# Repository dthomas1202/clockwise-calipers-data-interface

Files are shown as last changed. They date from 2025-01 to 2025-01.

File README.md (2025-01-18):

# Data Interface for Clockwise Tools Caliper Gauges

Easily transfer measurements from Clockwise Tools calipers to your computer for applications like measurement logging, CAD modeling, or manufacturing workflows.

This project is a reverse-engineered version of the Clockwise Tools DTCR-02 RS232 Data Cable for Clockwise tools DCLR-XX05 calipers.
And given the similarity to [liba2k's VINCA Reader](https://github.com/liba2k/VINCA_reader) it seems likely that this Data Interface will work with VINCA series calipers as well.

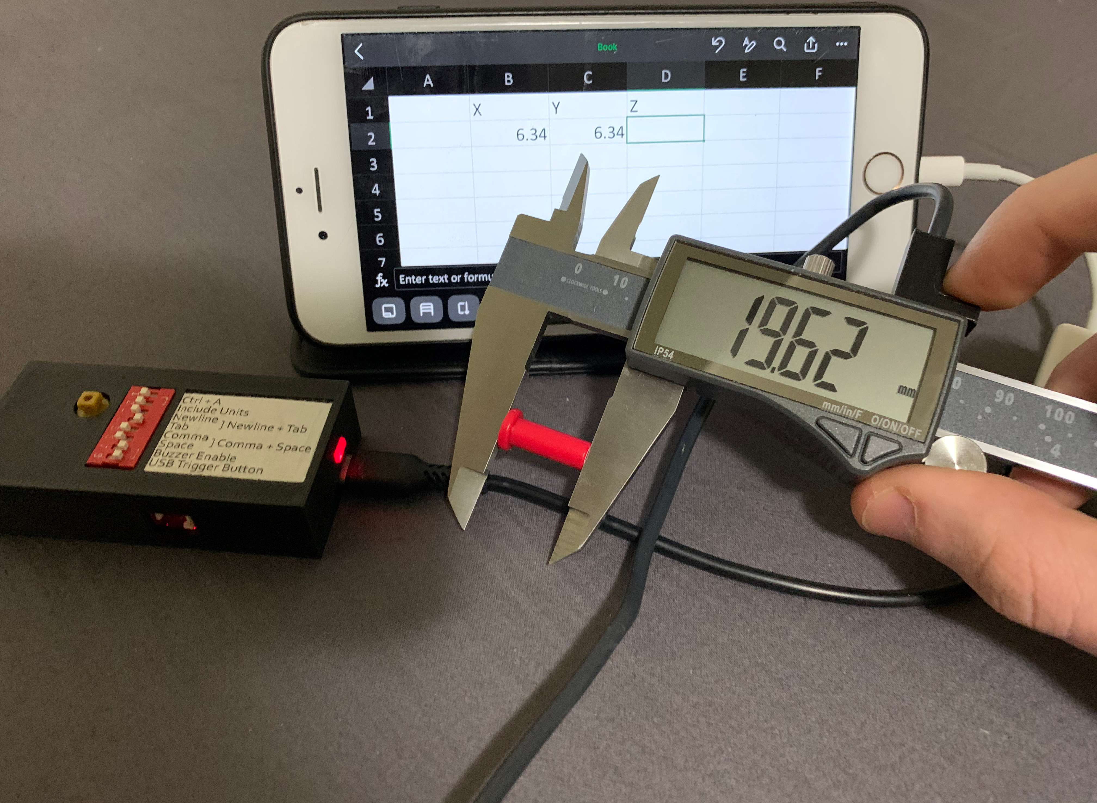
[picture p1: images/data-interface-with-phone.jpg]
Data Interface connected to a iPhone
|  |
|:-:|
| *Data Interface connected to a iPhone running Excel.* |

## Table of Contents

- [Data Interface for Clockwise Tools Caliper Gauges](#data-interface-for-clockwise-tools-caliper-gauges)
  - [Table of Contents](#table-of-contents)
  - [Features](#features)
  - [Hardware](#hardware)
    - [Arduino Support](#arduino-support)
    - [PCB](#pcb)
    - [Case \& USB Cable](#case--usb-cable)
  - [Technical Information](#technical-information)
    - [The "RS232" Serial Protocol](#the-rs232-serial-protocol)
      - [Signal Details](#signal-details)
      - [Protocol Details](#protocol-details)
    - [Potential Improvements](#potential-improvements)
  - [Quirks](#quirks)
    - [iOS Devices](#ios-devices)
    - [Android Devices](#android-devices)

## Features

This project improves on the DTCR-02 Data Cable with enhanced features and flexibility:

- Emulates a generic USB keyboard, compatible with Linux, Windows, macOS, iOS[^1], Android[^1], and really anything that supports USB keyboards.
- Captures and transfers the caliper measurement to any program, such as Excel or CAD software.
- Multiple ways to trigger measurement transfer:
  - Built-in push button.
  - External remote push button or foot pedal (via a 2-pin JST connector).
  - Custom USB cable with a button near the calipers (see schematics for details).
- DIP switch configurable options:
  - `CTRL + A` to overwrite previous measurements.
  - Append units (mm/in) to measurements (e.g., 1.23&nbsp;mm).
  - Add newline, tab, comma, or space after measurements.
  - Enable a buzzer to provide audible feedback when a measurement is sent.
  - Enable the trigger input on the USB ports VBUS pin (see schematics for details).
- Open source allowing full customizability for advanced use cases.

[^1]: See [Quirks](#quirks) for compatibility notes.

## Hardware

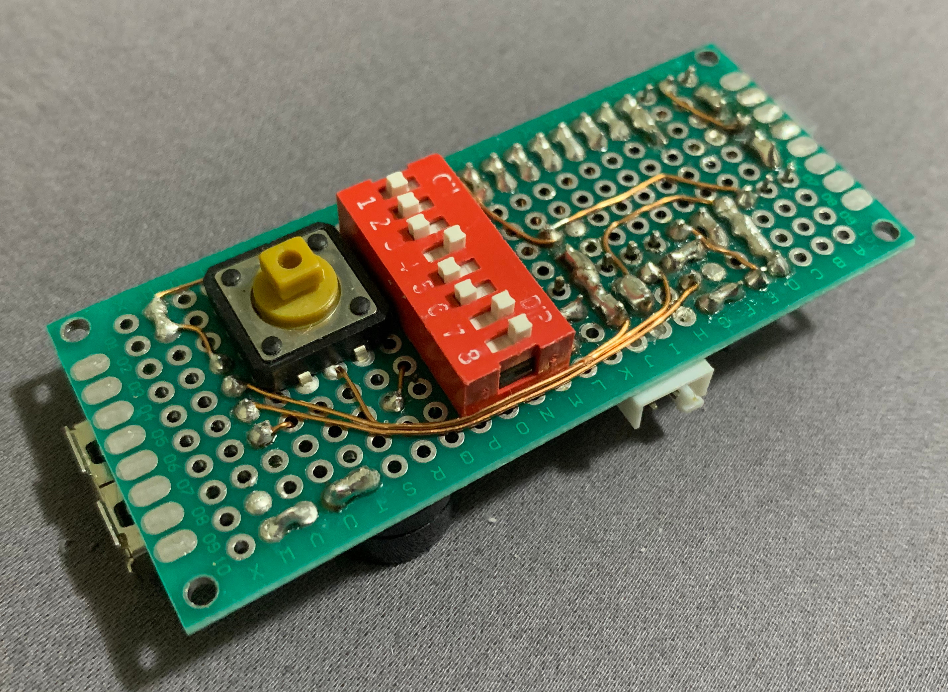
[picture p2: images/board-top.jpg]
Top side of board
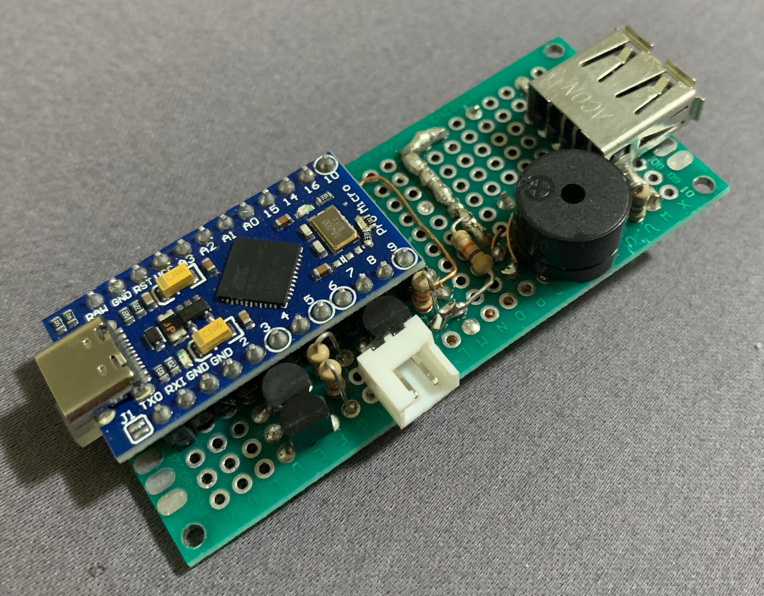
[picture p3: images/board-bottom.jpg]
Bottom side of board
|  |  |
|:-:|:-:|

### Arduino Support

Most Arduino's should be able to read the data stream from the calipers, as the clock rate is relatively slow.

However, in order to emulate a USB keyboard, the Arduino must support native USB communication (Micro, Pro Micro, Leonardo, etc.), or you must use something like [HoodLoader2](https://github.com/NicoHood/HoodLoader2) (See the [Arduino HID Project](https://github.com/NicoHood/HID) for compatibility).

### PCB

As part of the KiCad schematic, there is an example through-hole layout for a double-sided perfboard, as seen in the images above.

KiCad does not support making proper perfboard layouts, so the board is laid out as a PCB, but with components positioned on a 2.54&nbsp;mm grid.
If you intend fabricate an actual PCB, then you probably should not base it off of this.

### Case & USB Cable

3D models are also included for the case and the custom USB cable.
The case was designed to fit these [30x70&nbsp;mm perfboards](https://a.co/d/0OxZCzR) from Amazon, using the board layout provided in the schematic.

The USB cable was designed to fit a 6x6&nbsp;mm tactile push-button and a power only Micro-USB connector that I cut open to use the data pins.

> In both cases, you will likely have to make some modification to the 3D models to suit your own components.

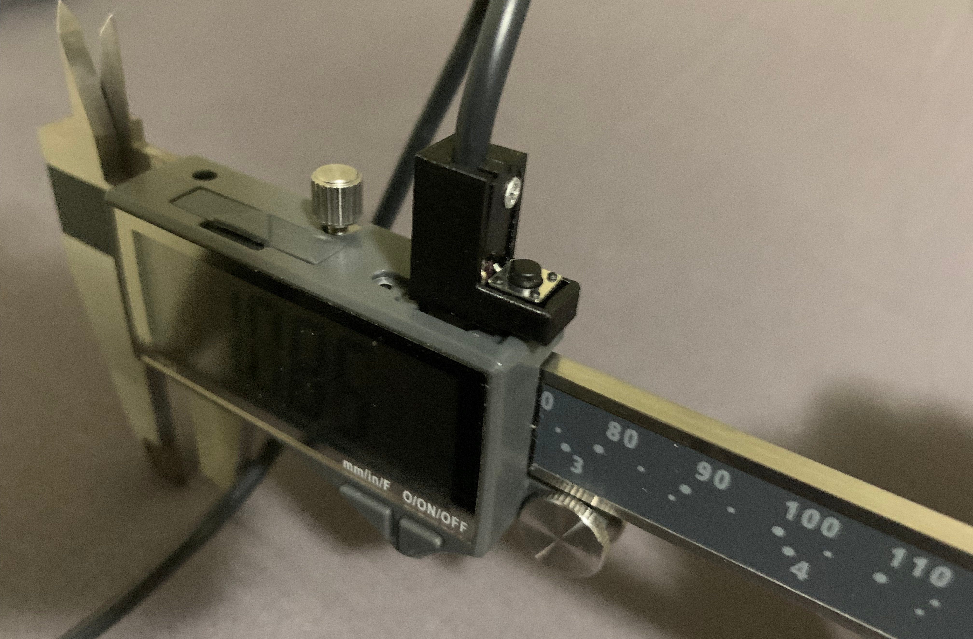
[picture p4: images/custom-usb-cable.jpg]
Custom designed USB cable end
|  |
|:-:|
| *Custom designed USB cable end with integrated trigger button* |

## Technical Information

### The "RS232" Serial Protocol

Clockwise Tools describes the communication as "RS232," but it uses synchronous serial communication over the USB D+ and D- pins. This is effectively equivalent to SPI.

#### Signal Details

- __Clock signal:__ USB D- pin, ~0.4&nbsp;ms per cycle, SPI Mode 3 equivalent.
- __Data signal:__ USB D+ pin, 24-bit (3 x 8-bit) packets, transmitted every ~150&nbsp;ms.
- __+1.5 V:__ USB VBUS pin, constant 1.5&nbsp;V supply.
- All pins operate at 1.5&nbsp;V.
- Clock and data are inverted due to the transistors used for level shifting. So SPI Mode 1 is used in software, and the serial data is inverted.
- Data is transmitted regardless of if the calipers are turned on or not.

> [!WARNING]
> The calipers exhibit weird behavior when too much current is drawn over the USB port.
> This can cause measurements to fluctuate significantly, or the screen to dim.
> Anything connected to the calipers USB port must not draw over __~0.3&nbsp;mA__ of current from all of its pins combined.
> This means that the parallel resistance between VBUS, D+, and D- to GND of the USB connector must be at least ~5&nbsp;kΩ, but preferably well above that.

As far as I can tell, there is no way to communicate from the host device to the calipers, as they are constantly transmitting on D+ and D-, and due to the above, pulling VBUS low causes the calipers to lose power.

#### Protocol Details

- First 4 bits are flags:
  - __Unit:__ Millimeters if 0, Inches if 1.
  - (Unknown use)
  - (Unknown use)
  - __Sign:__ Positive if 0, Negative if 1.
- Last 20 bits are fixed point measurement data:
  - In either hundredths of a millimeter, or
  - 1/2 thousandths of an inch.

The full details are laid out in this article: [Harbor Freight Caliper Data Format](https://www.yuriystoys.com/2013/07/chinese-caliper-data-format.html).

The calipers will send whatever unit is currently selected on the display.
Note that the fraction mode is sent exactly the same as inches.
However, it sends updates less often in fractions mode, presumably since it has to do additional processing for the fractional conversion.

The full implementation of decoding and converting the 24-bit packets can be seen in `ClockwiseCaliper.cpp`.

### Potential Improvements

I designed the schematics and built the device using parts that I had lying around.
Mostly used parts taken from laser printers, coffee makers, and power supplies.
So, given access to the right parts, there are some improvements that can be made to the design.

- The three transistors used to do the voltage level shifting (__Q1__, __Q2__, and __Q3__ in the schematic) should be replaced by MOSFETs.
  The resistors for those transistors should be changed to around 1&nbsp;kΩ.
  And pull-down resistors for the MOSFETs should be added, with values around 100&nbsp;kΩ. This is because of the maximum current requirement as outlined above.

- The calipers can not source over 0.3&nbsp;mA of current from all of its pins, however, I have not tested how much current (if any) it can sink.
  This may be the preferred method for connecting if it works.

- The program could technically use the hardware SPI interface of the Arduino.
  However, without proper timing of the slave select signal, it can cause the data to get out of sync on the first byte.
  This could be solved by controlling the SPI slave select input using another output pin.
  Then activating it on the initial clock pulse, and deactivating it on the last clock pulse.
  However, ensure that the slave select pin is accessible, as Arduino Pro Micro's use that pin for an onboard LED.

## Quirks

### iOS Devices

iOS devices will complain if the USB device reports that it draws more than 100&nbsp;mA over the USB port.
By default, most Arduino's report their bMaxPower USB configuration descriptor to be 500&nbsp;mA.

To change the bMaxPower descriptor you have to change the line `#define USB_CONFIG_POWER (500)` to be 100 or less in `USBCore.h` of the Arduino core files.

Note that for iDevices with a lightning port, a Lightning to USB Camera Adapter (the one with only a USB port) will allow connecting the device, so long as it reports a lower power consumption.

Instead, I have heard that the Lightning to USB 3 Camera Adapter (the one with both a USB port and a lightning port) MAY allow devices that report more than 100&nbsp;mA to work, so long as a charging cable is plugged in.

### Android Devices

I have not tested any Android devices with the Data Interface, but I would assume that with the right adapter, and potentially the iOS bMaxPower tweak above that it would work.

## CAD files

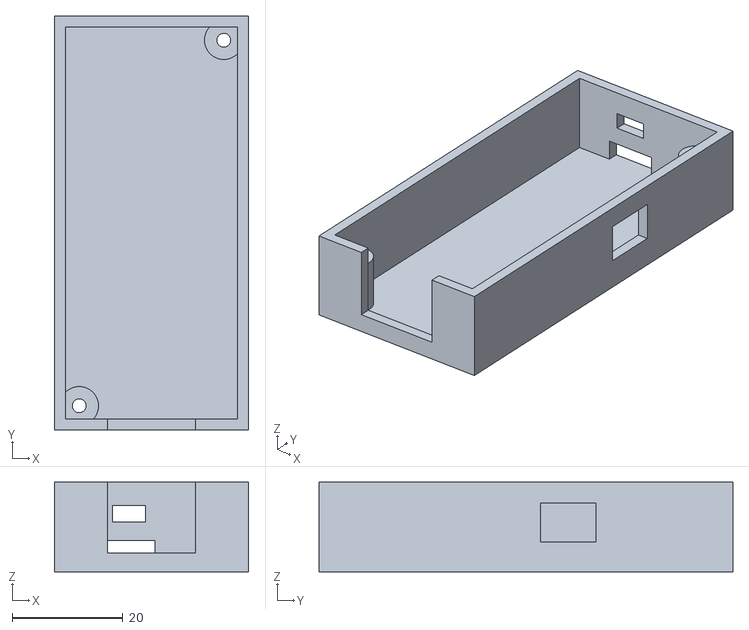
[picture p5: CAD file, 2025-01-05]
3d-models/Case Bottom.stl
35.2 x 74.9 x 16.2

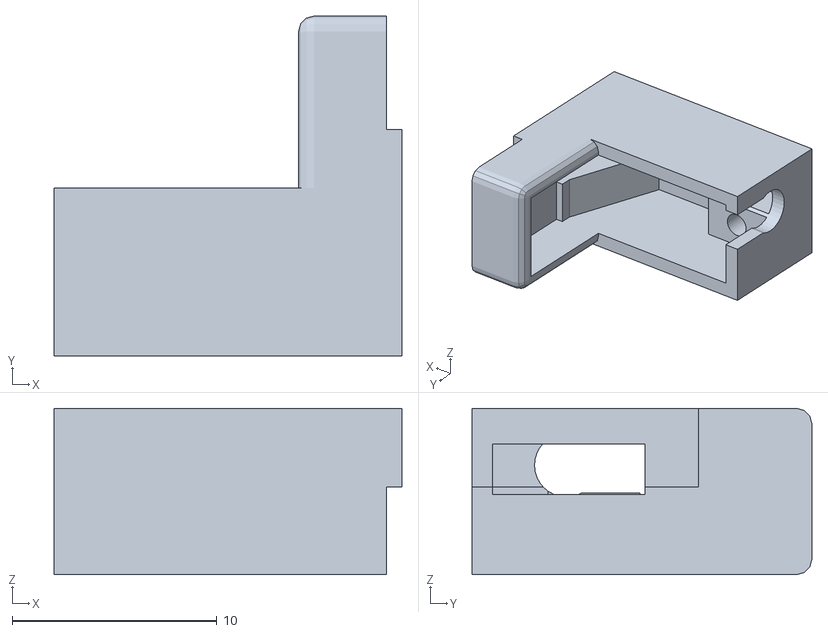
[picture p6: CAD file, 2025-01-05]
3d-models/usb-cable/USB Casing.stl
17.0 x 16.6 x 8.12

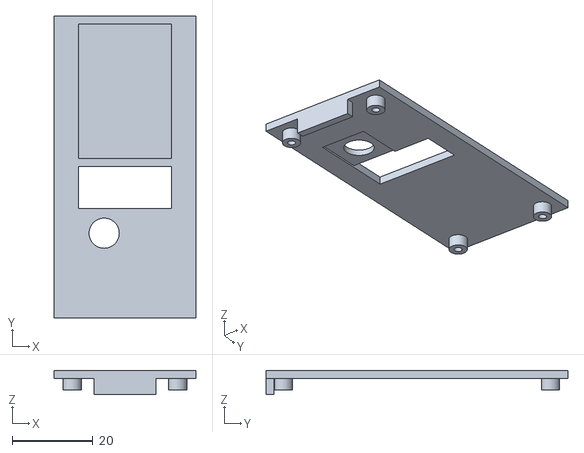
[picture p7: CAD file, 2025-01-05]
3d-models/Case Top.stl
35.2 x 74.9 x 6.00

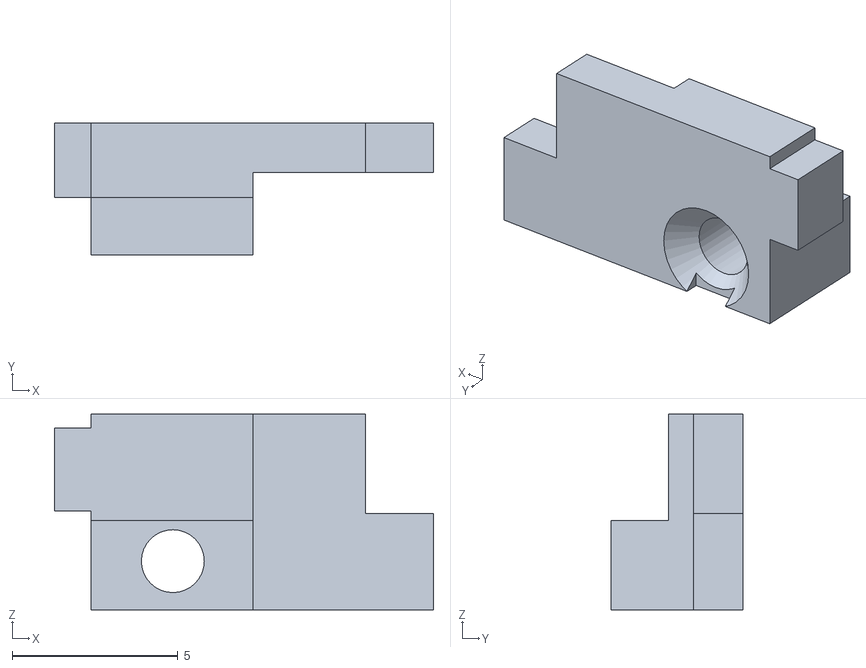
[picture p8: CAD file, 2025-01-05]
3d-models/usb-cable/Insert.stl
11.4 x 4.00 x 5.92

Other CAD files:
3d-models/Case.blend
3d-models/usb-cable/Usb Connector.blend

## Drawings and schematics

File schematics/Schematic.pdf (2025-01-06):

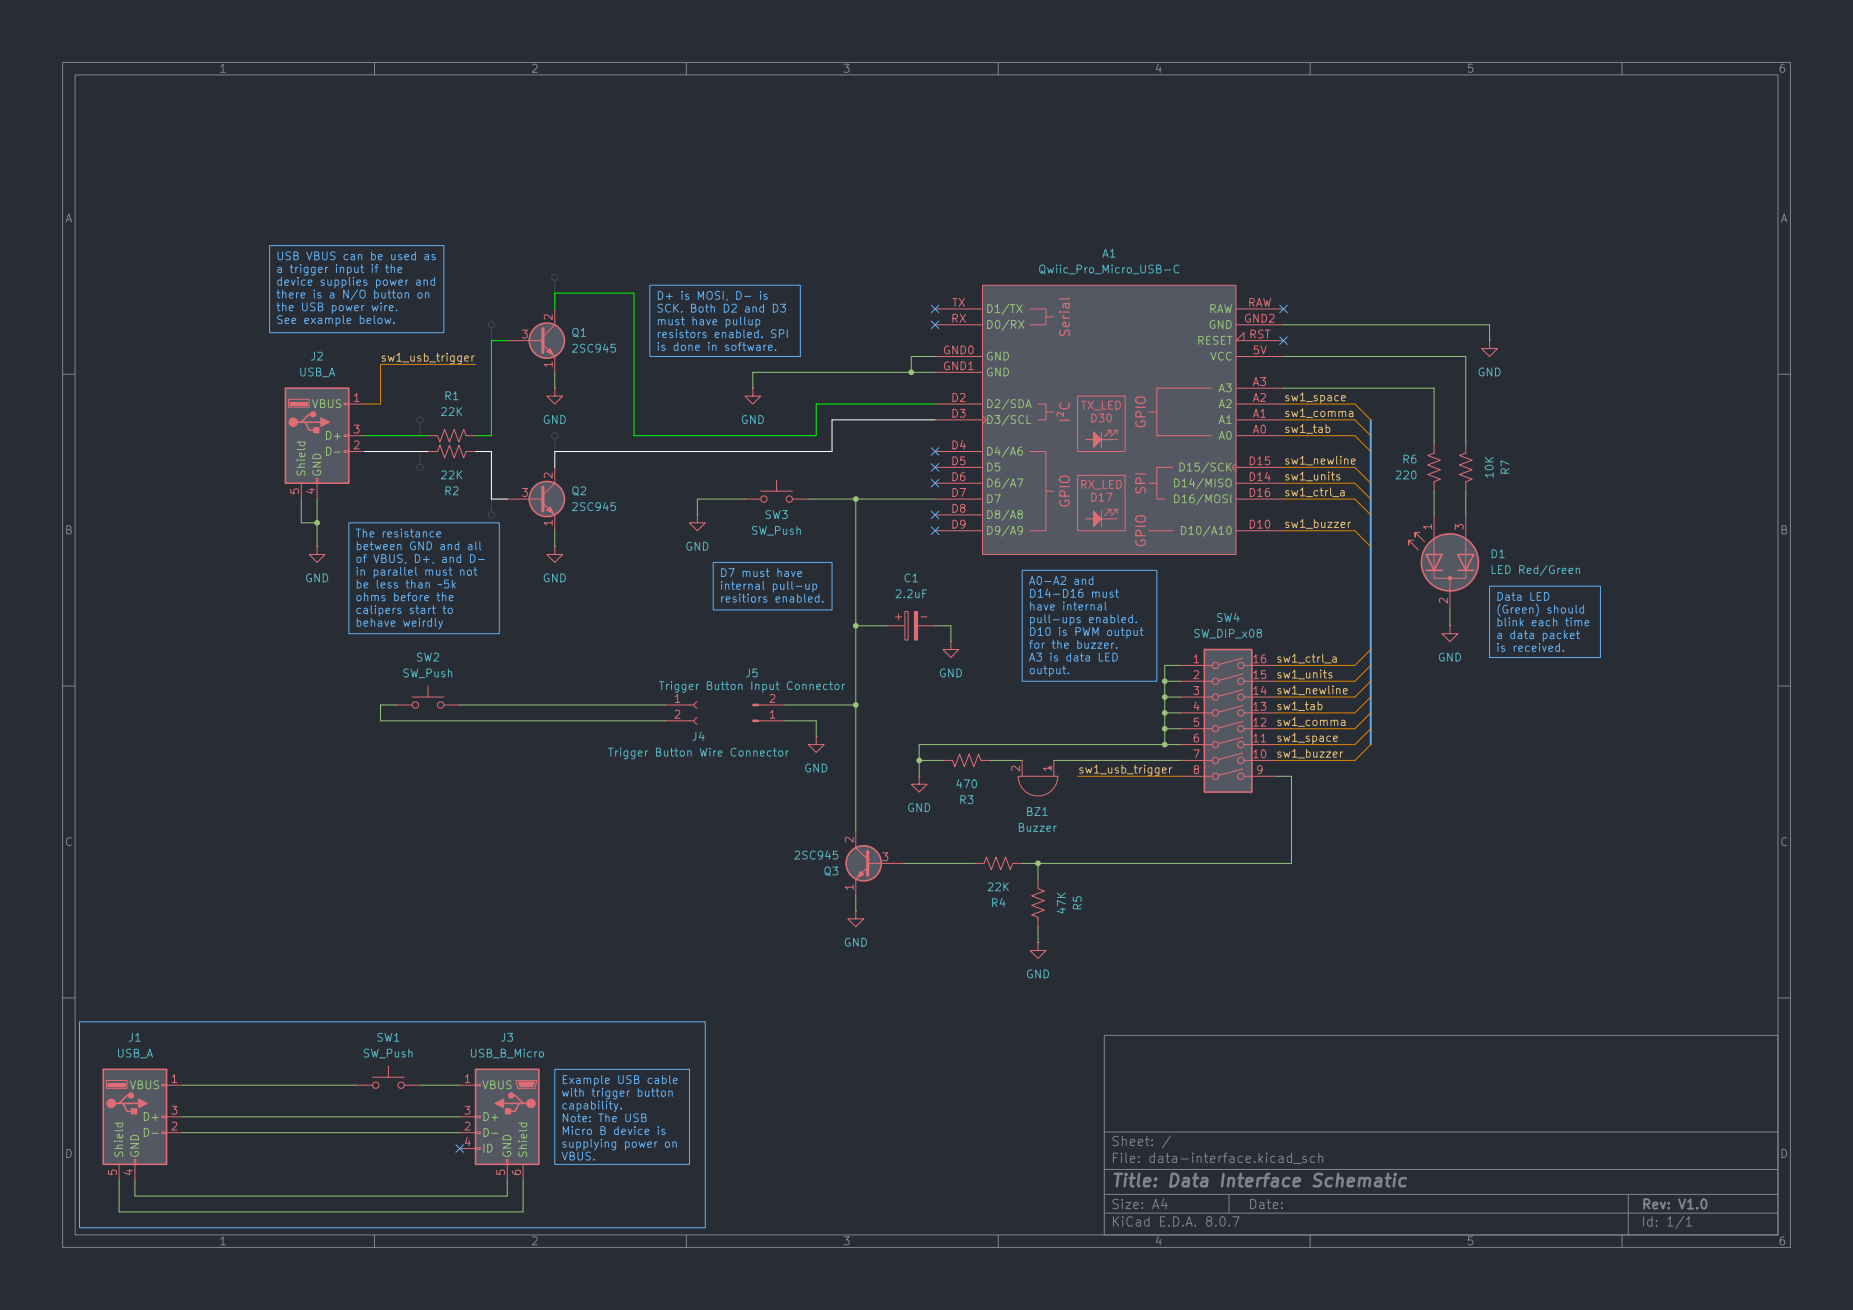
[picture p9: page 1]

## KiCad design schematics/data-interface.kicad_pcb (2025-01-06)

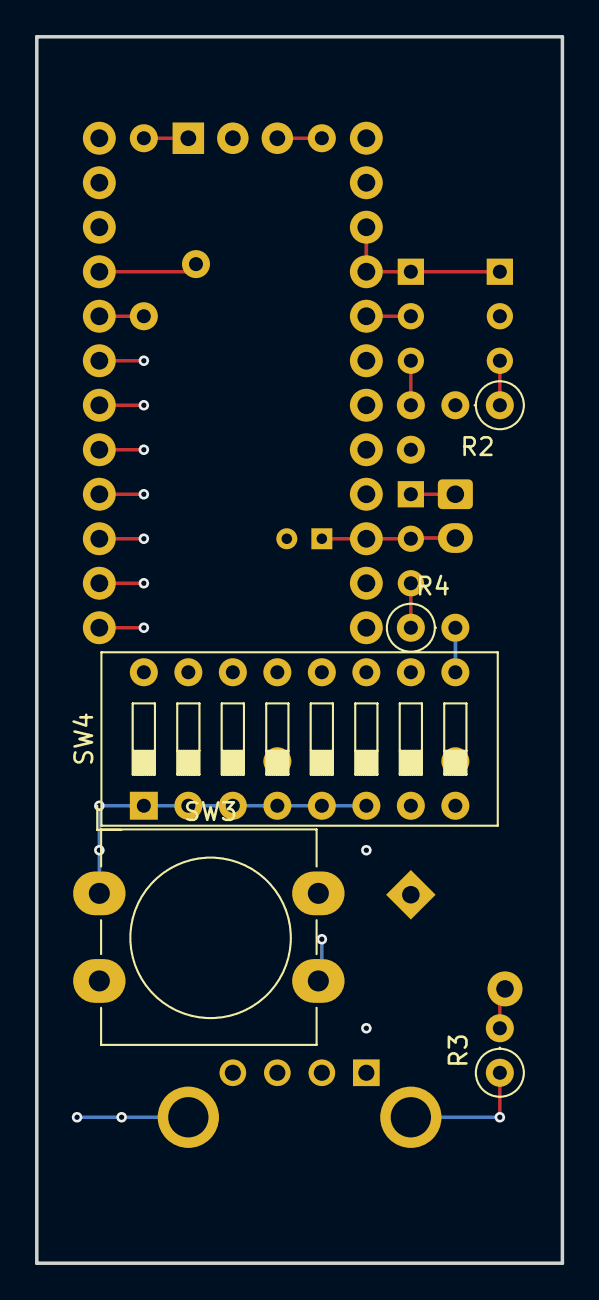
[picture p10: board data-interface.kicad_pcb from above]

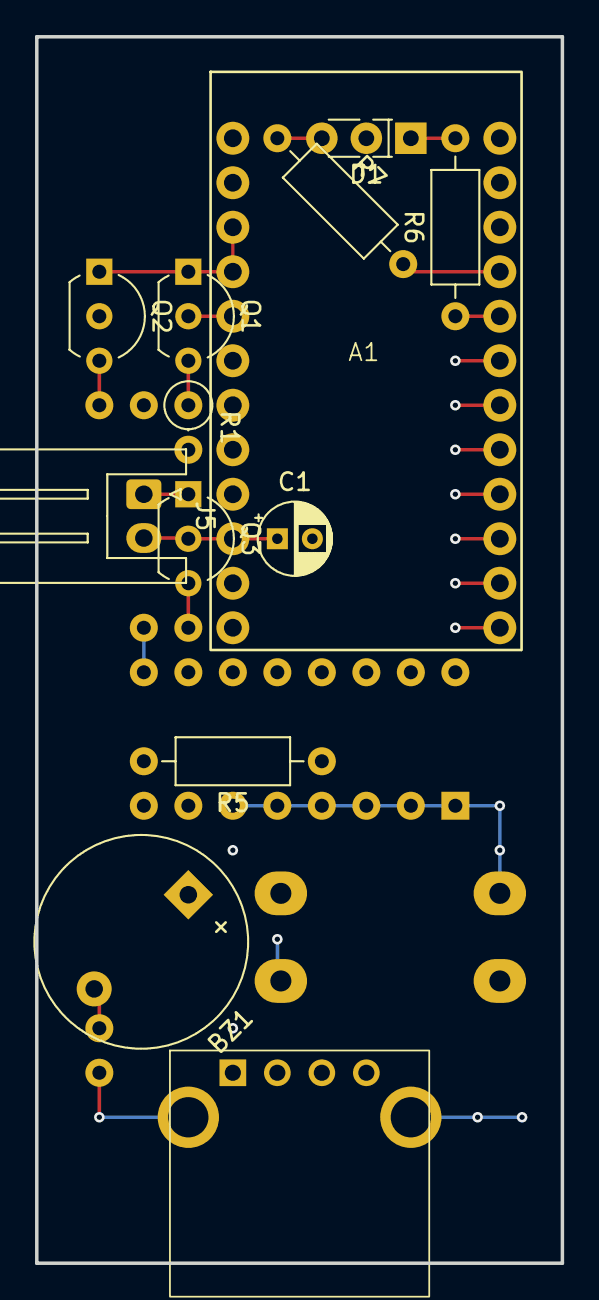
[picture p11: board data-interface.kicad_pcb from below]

Board: 4 copper layers, 30.0 x 70.0 mm, 18 parts (13 on the bottom side), 24 nets.

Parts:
A1: Qwiic_Pro_Micro_USB-C; Qwiic_Pro_Micro_USB-C_Socket
BZ1: Buzzer; Buzzer_12x9.5RM7.6
C1: 2.2uF; CP_Radial_D4.0mm_P2.00mm
D1: LED Red/Green; LED_Rectangular_W5.0mm_H2.0mm-3Pins
J2: USB_A; USB_A_Horizontal
J5: Trigger Button Input Connector; JST_XH_S2B-XH-A_1x02_P2.50mm_Horizontal
Q1, Q2, Q3: 2SC945; TO-92L_Inline_Wide
R1, R2, R4: 22K; R_Axial_DIN0207_L6.3mm_D2.5mm_P2.54mm_Vertical
R3: 470; R_Axial_DIN0207_L6.3mm_D2.5mm_P2.54mm_Vertical
R5: 47K; R_Axial_DIN0207_L6.3mm_D2.5mm_P10.16mm_Horizontal
R6: 220; R_Axial_DIN0207_L6.3mm_D2.5mm_P10.16mm_Horizontal
R7: 10K; R_Axial_DIN0207_L6.3mm_D2.5mm_P10.16mm_Horizontal
SW3: SW_Push; SW_PUSH-12mm_Wuerth-430476085716
SW4: SW_DIP_x08; SW_DIP_SPSTx08_Slide_9.78x22.5mm_W7.62mm_P2.54mm

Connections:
/sw1_buzzer: A1.D10 (D10/A10), SW4.10
/sw1_comma: A1.A1, SW4.12
/sw1_ctrl_a: A1.D16 (D16/MOSI), SW4.16
/sw1_newline: A1.D15 (D15/SCK), SW4.14
/sw1_space: A1.A2, SW4.11
/sw1_tab: A1.A0, SW4.13
/sw1_units: A1.D14 (D14/MISO), SW4.15
/sw1_usb_trigger: J2.1 (VBUS), SW4.8
GND: A1.GND0 (GND), A1.GND1 (GND), A1.GND2 (GND), C1.2, D1.2 (K), J2.4 (GND), J2.5 (Shield), J5.1, Q1.1 (E), Q2.1 (E), Q3.1 (E), R3.1, R5.1, SW3.1, SW4.1, SW4.2, SW4.3, SW4.4, SW4.5, SW4.6
unnamed: A1.D2 (D2/SDA), Q1.2 (C)
unnamed: A1.D3 (D3/SCL), Q2.2 (C)
unnamed: A1.A3, R6.1
unnamed: A1.5V (VCC), R7.2
unnamed: BZ1.1 (+), SW4.7
unnamed: BZ1.2 (-), R3.2
unnamed: D1.1 (A1), R6.2
unnamed: D1.3 (A2), R7.1
unnamed: J2.3 (D+), R1.2
unnamed: J2.2 (D-), R2.2
unnamed: A1.D7, C1.1, J5.2, Q3.2 (C), SW3.2
unnamed: Q1.3 (B), R1.1
unnamed: Q2.3 (B), R2.1
unnamed: Q3.3 (B), R4.1
unnamed: R4.2, R5.2, SW4.9

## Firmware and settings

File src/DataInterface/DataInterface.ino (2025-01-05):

/*
 * DataInterface.ino - Clockwise Calipers Data Interface
 * Copyright (C) 2025  Diesel Thomas
 *
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
 * You should have received a copy of the GNU General Public License
 * along with this program.  If not, see <https://www.gnu.org/licenses/>.
 */

/*
 * NOTE: To achieve compatibility with mobile devices, such as Apple
 * iDevices, the bMaxPower USB configuration descriptor must be lowered
 * so the device accepts the Arduino. Currently, to do this the line
 *   #define USB_CONFIG_POWER (500)
 * must be changed to less than 100 in USBCore.h of the Arduino core
 * library.
 */


#include "ClockwiseCaliper.h"
#include "SoftSPISlave.h"
#include <HID-Project.h>

// #define DEBUG_SERIAL

#ifdef DEBUG_SERIAL
    #define debug_println(...) Serial.println(__VA_ARGS__)
    #define debug_print(...) Serial.print(__VA_ARGS__)
#else
    #define debug_println(...)
    #define debug_print(...)
#endif


// Caliper SPI like data
const uint8_t CLK_PIN = 3; // Serial clock pin (must support interrupts)
const uint8_t DATA_PIN = 2; // Serial data pin (must support interrupts)
const uint32_t BIT_MAX_DELAY = 10; // Milliseconds - Maximum time between spi clock pulses
const uint32_t PACKET_MAX_DELAY = 10; // Milliseconds - Maximum time between 8 bit packets

// DIP switch control pins
const uint8_t DIP_CTRL_A_PIN = 16; // Type CTRL+A before the measurement
const uint8_t DIP_UNITS_PIN = 14; // Type the units after the measurement
const uint8_t DIP_NEWLINE_PIN = 15; // Type a newline after the measurement
const uint8_t DIP_TAB_PIN = A0; // Type a tab after the measurement
const uint8_t DIP_COMMA_PIN = A1; // Type a comma after the measurement
const uint8_t DIP_SPACE_PIN = A2; // Type a space after the measurement
// Any of newline, tab, comma, and space can be combined to in that order
const bool DIP_ON_STATE = LOW; // Switch is active when it is in this state

const uint8_t TRIGGER_PIN = 7; // Triggers typing the measurement (should support interrupts)
const uint8_t TRIGGER_PIN_INT_MODE = FALLING; // When to trigger the interrupt (either RISING or FALLING)
// NOTE: You can rewrite this for TRIGGER_PIN to not require interrupts, its just real convenient

const uint8_t DATA_LED_PIN = A3; // LED to blink when data is r * <one line to give the program's name and a brief idea of what it does.>
const bool DATA_LED_ACTIVE_STATE = HIGH; // State to use when data LED is ON

const uint8_t BUZZER_PIN = 10; // Passive buzzer to sound when data is typed (must support pwm)
const uint16_t BUZZER_FREQ = 4000; // Hz - Frequency of buzzer
const uint16_t BUZZER_DURATION = 10; // Milliseconds - Time to sound the buzzer for


uint8_t resyncCounter = 0;
volatile bool triggerFlag = false;

ClockwiseCaliper caliper;
SoftSPISlave softSpi(CLK_PIN, -1, DATA_PIN, -1);


void triggerIsr() {
    triggerFlag = true;
}


void setup() {
    #ifdef DEBUG_SERIAL
        Serial.begin(115200);

        while (!Serial && millis() < 2000) {
            ; // Wait for serial port to connect, or 2 seconds. Needed for native USB
        }
    #endif

    softSpi.begin(false, SSPI_MODE1, SSPI_LSB_FIRST, BIT_MAX_DELAY);

    // Override pinMode from softSpi to enable pullups
    pinMode(CLK_PIN, INPUT_PULLUP);
    pinMode(DATA_PIN, INPUT_PULLUP);

    pinMode(DIP_CTRL_A_PIN, INPUT_PULLUP);
    pinMode(DIP_UNITS_PIN, INPUT_PULLUP);
    pinMode(DIP_NEWLINE_PIN, INPUT_PULLUP);
    pinMode(DIP_TAB_PIN, INPUT_PULLUP);
    pinMode(DIP_COMMA_PIN, INPUT_PULLUP);
    pinMode(DIP_SPACE_PIN, INPUT_PULLUP);

    pinMode(TRIGGER_PIN, INPUT_PULLUP);

    pinMode(DATA_LED_PIN, OUTPUT);
    pinMode(BUZZER_PIN, OUTPUT);

    digitalWrite(DATA_LED_PIN, !DATA_LED_ACTIVE_STATE);

    BootKeyboard.begin();

    debug_println("Starting...");

    tone(BUZZER_PIN, BUZZER_FREQ, BUZZER_DURATION);
    delay(200);
    tone(BUZZER_PIN, BUZZER_FREQ, BUZZER_DURATION);

    // Set last so pins stabilize
    attachInterrupt(digitalPinToInterrupt(TRIGGER_PIN), triggerIsr, TRIGGER_PIN_INT_MODE);
}


void emptySoftSpiBuffer() {
    // Empty RX buffer, we don't know which byte is which
    while (softSpi.rxBytesAvailable() > 0) {
        softSpi.read();
    }
}


void recievePacket() {
    static uint8_t spiDataIndex = 0;
    static uint32_t lastSpiDataTime = 0;

    uint8_t spiData = ~ softSpi.read(); // Invert all bits
    uint32_t currentTime = millis();

    digitalWrite(DATA_LED_PIN, DATA_LED_ACTIVE_STATE);

    if (spiDataIndex > 0 && currentTime - lastSpiDataTime >= PACKET_MAX_DELAY) {
        // Time between packets was too long, resync
        resyncCounter++;
        spiDataIndex = 0;
    }

    caliper.updateByte(spiData, spiDataIndex);
    spiDataIndex++;
    lastSpiDataTime = currentTime;

    if (spiDataIndex >= caliper.getPacketLength()) {
        // Completed packet, reset and update
        spiDataIndex = 0;

        caliper.setNewData();
        digitalWrite(DATA_LED_PIN, !DATA_LED_ACTIVE_STATE);
    }
}


void typeIfPin(KeyboardKeycode key, uint8_t pin) {
    if (digitalRead(pin) == DIP_ON_STATE) {
        BootKeyboard.write(key);
    }
}


void typeMeasurement() {
    // CTRL + A
    if (digitalRead(DIP_CTRL_A_PIN) == DIP_ON_STATE) {
        BootKeyboard.press(KEY_LEFT_CTRL);
        BootKeyboard.press(KEY_A);
        BootKeyboard.releaseAll();
    }

    // Type measurement
    BootKeyboard.print(caliper.getMeasurement(), 4);

    // Units
    if (digitalRead(DIP_UNITS_PIN) == DIP_ON_STATE) {
        BootKeyboard.print(caliper.getUnitString());
    }

    typeIfPin(KEY_ENTER, DIP_NEWLINE_PIN); // Newline
    typeIfPin(KEY_TAB, DIP_TAB_PIN);       // Tab
    typeIfPin(KEY_COMMA, DIP_COMMA_PIN);   // Comma
    typeIfPin(KEY_SPACE, DIP_SPACE_PIN);   // Space

    tone(BUZZER_PIN, BUZZER_FREQ, BUZZER_DURATION);
}


void loop() {
    if (softSpi.rxHasLostData()) {
        emptySoftSpiBuffer();
        debug_println("Lost data, buffer emptied");
    }

    while (softSpi.rxHasData()) {
        recievePacket();
    }

    if (caliper.isNewData()) {
        // Always maintain most recent data
        caliper.refershData();

        debug_print("resync: ");     debug_print(resyncCounter);            debug_print(", ");
        debug_print("spi_resync: "); debug_print(softSpi.getResyncCount()); debug_print(", ");

        debug_print("unit: "); debug_print(caliper.getUnitString());     debug_print(", ");
        debug_print("sign: "); debug_print(caliper.getSignString());     debug_print(", ");
        debug_print("raw: ");  debug_print(caliper.getRawMeasurement()); debug_print(", ");

        debug_print("measurement: "); debug_print(caliper.getMeasurement(), 4); debug_println();
    }

    if (triggerFlag) {
        triggerFlag = false;
        typeMeasurement();
        debug_println("Typed measurement");
    }
}

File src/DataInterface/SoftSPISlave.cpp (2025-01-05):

/*
 * SoftSPISlave.cpp - SPI Slave Implemented in Software
 * Copyright (C) 2025  Diesel Thomas
 *
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
 * You should have received a copy of the GNU General Public License
 * along with this program.  If not, see <https://www.gnu.org/licenses/>.
 */

// WARNING: TX (MISO) functionality is currently untested, as it was only
// implemented for completeness


#include "SoftSPISlave.h"


/**
 * Software SPI slave constructor.
 * The CLK pin must be defined and must be an interrupt capable pin.
 * MISO, MOSI, and SS pins are optional, however, at least one of MISO
 * or MOSI must be defined. Also, if MISO is defined then SS must also
 * be defined and must be an interrupt capable pin.
 *
 * @param clkPin serial clock pin
 * @param misoPin master in, slave out pin
 * @param mosiPin master out, slave in pin
 * @param ssPin slave select pin
 */
SoftSPISlave::SoftSPISlave(int16_t clkPin,
                           int16_t misoPin = -1,
                           int16_t mosiPin = -1,
                           int16_t ssPin = -1) {
    this->clkPin = clkPin;
    this->misoPin = misoPin;
    this->mosiPin = mosiPin;
    this->ssPin = ssPin;


    this->dataIndex = 0;
    this->resyncCount = 0;
    this->rxDataLost = false;
}


/**
 * Starts sending or receiving data on the SPI bus.
 * maxClkTime defines the maximum time to wait for the next clock change
 * while in the middle of a byte. If the time elapses, the current byte
 * is reset to the start for the next clock cycle.
 *
 * @param ssActiveHigh if true, slave select is active when high
 * @param spiMode the SPI clock polarity and phase to use
 * @param spiDataOrder whether the LSB or MSB is first
 * @param maxClkTime milliseconds to wait for another clock before
 *                   resetting. A value of 0 disables this
 */
void SoftSPISlave::begin(bool ssActiveHigh = false,
                         softspi_mode_t spiMode = SSPI_MODE0,
                         softspi_data_order_t spiDataOrder = SSPI_MSB_FIRST,
                         uint32_t maxClkTime = 0) {
    this->ssActiveHigh = ssActiveHigh;
    this->spiCPHA = SoftSPISlave::getBit(spiMode, 0);
    this->spiCPOL = SoftSPISlave::getBit(spiMode, 1);
    this->spiDataOrder = spiDataOrder;
    this->maxClkTime = maxClkTime;

    int16_t clkIntPin = digitalPinToInterrupt(this->clkPin);
    int16_t ssIntPin = digitalPinToInterrupt(this->ssPin);

    if (clkIntPin < 0 // CLK pin is not set, or not an interrupt capable pin
            || (this->misoPin < 0 && this->mosiPin < 0) // At least one of MISO or MOSI is not set
            || (this->misoPin >= 0 && ssIntPin < 0)) { // MISO is defined and SS is not defined or not interrupt capable
        return;
    }

    pinMode(this->clkPin, INPUT);

    if (this->mosiPin >= 0) {
        pinMode(this->mosiPin, INPUT);
    }

    if (this->ssPin >= 0) {
        // SS is defined
        pinMode(this->ssPin, INPUT);

        if (this->misoPin >= 0 && ssIntPin >= 0) {
            // MISO is defined and SS is interrupt capable
            attachInterrupt(ssIntPin, bindArgGateThisAllocate(&SoftSPISlave::ssIsr, this), CHANGE);
        }
    }

    attachInterrupt(clkIntPin, bindArgGateThisAllocate(&SoftSPISlave::clkIsr, this), CHANGE);
}

/**
 * Stops sending or receiving data on the SPI bus.
 */
void SoftSPISlave::end() {
    int16_t clkIntPin = digitalPinToInterrupt(this->clkPin);
    int16_t ssIntPin = digitalPinToInterrupt(this->ssPin);

    detachInterrupt(clkIntPin);

    if (this->misoPin >= 0 && ssIntPin >= 0) {
        // SS would have been setup with interrupts
        detachInterrupt(ssIntPin);
    }

    // Only MISO is ever an output
    pinMode(this->misoPin, INPUT);
}


/**
 * Returns the number of bytes that can be read.
 *
 * @return the number of bytes that can be read
 */
uint8_t SoftSPISlave::rxBytesAvailable() {
    return this->rxBuff.size();
}

/**
 * Returns the remaining number of bytes that can be received without
 * overwriting.
 *
 * @return the remaining space in the RX buffer
 */
uint8_t SoftSPISlave::rxBytesRemaining() {
    return this->rxBuff.available();
}

/**
 * Returns true if data is available to be read.
 *
 * @return true if data is available to be read
 */
bool SoftSPISlave::rxHasData() {
    return !this->rxBuff.isEmpty();
}

/**
 * Returns true if data has been lost since the last time this was
 * called.
 *
 * @return true if data has been lost
 */
bool SoftSPISlave::rxHasLostData() {
    bool retVal = this->rxDataLost;

    this->rxDataLost = false;

    return retVal;
}

/**
 * Reads a byte from the receive buffer.
 *
 * @return a byte from the receive buffer
 */
uint8_t SoftSPISlave::read() {
    return this->rxBuff.shift();
}

/**
 * Reads a byte from the receive buffer without removing it.
 *
 * @return a byte from the receive buffer
 */
uint8_t SoftSPISlave::peek() {
    return this->rxBuff.first();
}


/**
 * Returns the remaining number of bytes that can be added to the transmit
 * buffer without blocking.
 *
 * @return bytes available in the transmit buffer
 */
uint8_t SoftSPISlave::txBytesAvailable() {
    return this->txBuff.available();
}

/**
 * Returns true if the transmit buffer is full.
 *
 * @return true if the transmit buffer is full
 */
bool SoftSPISlave::txIsFull() {
    return this->txBuff.isFull();
}

/**
 * Adds a byte to the transmit buffer.
 *
 * @param data the byte to enqueue
 */
void SoftSPISlave::write(uint8_t data) {
    this->txBuff.push(data);
}

/**
 * Returns the count of timeouts due to maxClkTime.
 * NOTE: the count wraps at 255.
 *
 * @return the count of timeouts due to maxClkTime
 */
uint8_t SoftSPISlave::getResyncCount() {
    return this->resyncCount;
}
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

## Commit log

2024-12-04 Work on schematic
    [data-interface-schematics.kicad_pcb, data-interface-schematics.kicad_sch]
2024-12-07 Changes to schematics
    [data-interface-schematics.kicad_pcb, data-interface-schematics.kicad_sch]
2024-12-19 Added mock 3D model of case, updated schematic
    [Case.blend, data-interface-schematics.kicad_sch]
2025-01-05 Updated schematics
    [data-interface-schematics.kicad_pcb, data-interface-schematics.kicad_sch, data-interface.kicad_pcb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]
2025-01-05 Added 3d models and blender files
    [Case Bottom.stl, Case Top.stl, Case.blend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]
2025-01-06 Fixed minor errors in schematics
    [data-interface.kicad_pcb, data-interface.kicad_sch]

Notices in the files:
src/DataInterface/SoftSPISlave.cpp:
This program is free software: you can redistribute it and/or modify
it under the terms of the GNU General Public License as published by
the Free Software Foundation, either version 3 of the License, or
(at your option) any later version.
